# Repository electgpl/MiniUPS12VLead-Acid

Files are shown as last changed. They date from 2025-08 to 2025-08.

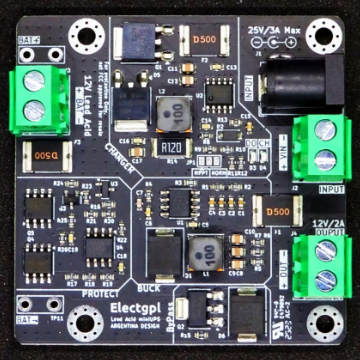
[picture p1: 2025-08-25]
Resources/Captura de pantalla 2025-08-25 201650.png

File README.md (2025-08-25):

# Mini UPS 12V Lead-Acid | UVP Protector - Buck - Charger - Bypass

This project implements a **mini uninterruptible power supply (UPS)** designed for **12V Lead-Acid AGM/GEL batteries**.  
It integrates a dedicated **CN3767 lead-acid charger**, a **PMOS + Schottky bypass circuit**, a **TPS54360 buck regulator**, and an **undervoltage protection (UVP)** stage to ensure safe battery operation.  

The design focuses on maintaining stable 12V output while protecting the battery from undervoltage damage and ensuring correct charging cycles.  

---

## 🔑 Features

- **Battery chemistry supported:** 12V Lead-Acid (AGM, GEL).  
- **CN3767-based lead-acid charger** with constant-current/constant-voltage (CC/CV) charging.  
- **Bypass system:**  
  - PMOS + Schottky switch circuit.  
  - During charging, disconnects the battery from the load to allow proper charging.  
  - The load is powered instead by a regulated buck supply.  
- **Buck regulator stage:**  
  - Based on **TPS54360** DC/DC converter.  
  - Configured to **13.8V output** for stable system powering during battery charge.  
- **Undervoltage protection (UVP):**  
  - Implemented with **LM393 comparator** and **TL431 reference**.  
  - Controls a **back-to-back PMOS switch**.  
  - Cuts off the battery when voltage falls below **11V**.  
  - Latch-off behavior: system remains disconnected until external power is restored.  
- **2-layer PCB**, designed for compact size, thermal management, and robust operation.  

---

## 📂 Repository structure

- **/schematic/** → Circuit schematic files.  
- **/pcb/** → PCB layout files ready for fabrication.  
- **/doc/** → Technical notes and design explanation.  
- **/img/** → PCB renders and prototype photos.  

---

## 🔧 Typical applications

- DIY 12V backup supply for small systems.  
- Router, modem, or IoT device UPS.  
- Low-power embedded controllers requiring uninterrupted 12V operation.  
- Safe battery-powered test benches.  

---

## 📑 References

- [CN3767 Datasheet (Consonance)](http://www.consonance-elec.com/pdf/datasheet/DSE-CN3767.pdf)  
- [TPS54360 Datasheet (Texas Instruments)](https://www.ti.com/lit/ds/symlink/tps54360.pdf)  
- [LM393 Datasheet (Texas Instruments)](https://www.ti.com/lit/ds/symlink/lm393.pdf)  
- [TL431 Reference Datasheet (Texas Instruments)](https://www.ti.com/lit/ds/symlink/tl431.pdf)  

---

## 📸 Project preview

*(Insert here PCB renders and/or real prototype images)*  

---

## ⚖️ License

This project is released under the **MIT License**.  
You are free to use, modify, and distribute it, provided that proper credit is given.  

---

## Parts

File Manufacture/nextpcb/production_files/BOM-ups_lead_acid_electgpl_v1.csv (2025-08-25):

MPN | Qty | Designator | value | manufacturer | Category | SKU | Customer Supply | Customer Remark
 | 13 | C4,C2,C18,C1,C19,C6,C15,C13,C7,C3,C14,C16,C5 | 2u2
 | 6 | C11,C8,C17,C12,C10,C9 | 47u
 | 1 | D2 | 5V1
 | 2 | D4,D3 | LED
 | 2 | D5,Q1 | MBRD20100CT
 | 2 | D6,D1 | SS54
 | 3 | F1,F2,F3 | 500/24N
 | 4 | H1,H3,H4,H2 | MountingHole_Pad
 | 1 | J1 | Barrel_Jack_Switch
 | 3 | J2,J4,J3 | Screw_Terminal_01x02
 | 1 | JP1 | MPPT
 | 2 | L2,L1 | 10u
 | 1 | Q2 | NTF6P02
 | 2 | Q3,U3 | 2N7002
 | 2 | Q4,Q5 | AO4407
 | 25 | R11,R8,R1,R25,R13,R21,R26,R3,R6,R10,R19,R24,R12,R22,R17,R4,R15,R5,R7,R2,R9,R20,R16,R23,R18 | 100k
 | 1 | R14 | 0R12
 | 2 | TP11,TP10 | TestPoint_Alt
 | 1 | U1 | TPS54360DDA
 | 1 | U2 | CN3767
 | 1 | U4 | LM393

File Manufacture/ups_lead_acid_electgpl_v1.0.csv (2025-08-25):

Qty | Reference | Value | Footprint | DNP | LCSC | MFR P/N
4 | C1,C2,C3,C4 | 2u2 | Capacitor_SMD:C_0603_1608Metric |  | C913904 | CL10A225KB8NNNC
5 | C5,C13,C14,C16,C18 | 100n | Capacitor_SMD:C_0603_1608Metric |  | C1591 | CL10B104KB8NNNC
1 | C6 | 4n7 | Capacitor_SMD:C_0603_1608Metric |  | C1621 | CL10B472KB8NNNC
1 | C7 | 47p | Capacitor_SMD:C_0603_1608Metric |  | C1671 | CL10C470JB8NNNC
6 | C8,C9,C10,C11,C12,C17 | 47u | Capacitor_SMD:C_0805_2012Metric |  | C602037 | CL21A226MAYNNNE
1 | C15 | 220n | Capacitor_SMD:C_0603_1608Metric |  | C64705 | CL10B224KB8NNNC
1 | C19 | 10n | Capacitor_SMD:C_0603_1608Metric |  | C1589 | CL10B103KB8NNNC
2 | D1,D6 | SS54 | Diode_SMD:D_SMC |  | C5199108 | SS54
1 | D2 | 5V1 | Diode_SMD:D_SOD-123 |  | C66198 | MMSZ5231BT1G
2 | D3,D4 | LED | LED_SMD:LED_0603_1608Metric |  | C965802 | XL-1608UYC-06
1 | D5 | MBRD20100CT | Package_TO_SOT_SMD:TO-252-2 |  | C460890 | MBRD20100CT-13
3 | F1,F2,F3 | 500/24N | Fuse:Fuse_2920_7451Metric |  | C6165172 | SMD2920-500/24N
4 | H1,H2,H3,H4 | MountingHole_Pad | MountingHole:MountingHole_3.2mm_M3_Pad_Via | DNP
1 | J1 | Barrel_Jack_Switch | Connector_BarrelJack:BarrelJack_GCT_DCJ200-10-A_Horizontal |  | C194407 | DC-470-2.1GP
3 | J2,J3,J4 | Screw_Terminal_01x02 | TerminalBlock_RND:TerminalBlock_RND_205-00232_1x02_P5.08mm_Horizontal |  | C8465 | WJ500V-5.08-2P
1 | JP1 | MPPT | Jumper:SolderJumper-3_P1.3mm_Open_Pad1.0x1.5mm | DNP
2 | L1,L2 | 10u | Inductor_SMD:L_Taiyo-Yuden_NR-60xx |  | C360734 | VLS6045EX-100M
1 | Q1 | DMP4051LK3-13 | Package_TO_SOT_SMD:TO-252-2 |  | C397952 | DMP4051LK3-13
1 | Q2 | NTF6P02 | Package_TO_SOT_SMD:SOT-223-3_TabPin2 |  | C558214 | NTF6P02T3G-VB
1 | Q3 | 2N7002 | Package_TO_SOT_SMD:SOT-23 |  | C65189 | 2N7002,215
2 | Q4,Q5 | AO4407 | Package_SO:SOP-8_3.9x4.9mm_P1.27mm |  | C2841482 | AO4407A
1 | R1 | 442k | Resistor_SMD:R_0603_1608Metric |  | C23175 | 0603WAF4423T5E
1 | R2 | 90k9 | Resistor_SMD:R_0603_1608Metric |  | C2930136 | FRC0603F9092TS
1 | R3 | 243k | Resistor_SMD:R_0603_1608Metric |  | C7467321 | FRC0603F2433TS
1 | R4 | 16k9 | Resistor_SMD:R_0603_1608Metric |  | C2933158 | FRC0603F1692TS
1 | R5 | 49R9 | Resistor_SMD:R_0603_1608Metric |  | C2930110 | FRC0603F49R9TS
1 | R6 | 33k | Resistor_SMD:R_0603_1608Metric |  | C2907153 | FRC0603J333 TS
1 | R7 | 2k2 | Resistor_SMD:R_0603_1608Metric |  | C2907117 | FRC0603J222 TS
3 | R8,R11,R15 | 100k | Resistor_SMD:R_0603_1608Metric |  | C2907088 | FRC0603J104 TS
1 | R9 | 1M | Resistor_SMD:R_0603_1608Metric |  | C2907003 | FRC0603F1004TS
1 | R10 | 360k | Resistor_SMD:R_0603_1608Metric |  | C2907029 | FRC0603F3603TS
6 | R12,R16,R22,R23,R24,R26 | 10k | Resistor_SMD:R_0603_1608Metric |  | C2930027 | FRC0603J103 TS
1 | R13 | 120R | Resistor_SMD:R_0603_1608Metric |  | C2907096 | FRC0603J121 TS
1 | R14 | 0R12 | Resistor_SMD:R_2512_6332Metric |  | C875871 | PT2512FK-7W0R12L
3 | R17,R18,R19 | 47k | Resistor_SMD:R_0603_1608Metric |  | C2907042 | FRC0603F4702TS
1 | R20 | 15k | Resistor_SMD:R_0603_1608Metric |  | C2906995 | FRC0603F1502TS
1 | R21 | 4k7 | Resistor_SMD:R_0603_1608Metric |  | C2907166 | FRC0603J472 TS
1 | R25 | 10R | Resistor_SMD:R_0603_1608Metric |  | C2907091 | FRC0603J100 TS
2 | TP10,TP11 | TestPoint_Alt | TestPoint:TestPoint_Bridge_Pitch5.08mm_Drill1.3mm | DNP
1 | U1 | TPS54360DDA | Package_SO:HSOP-8-1EP_3.9x4.9mm_P1.27mm_EP2.41x3.1mm_ThermalVias |  | C44377 | TPS54360DDAR
1 | U2 | CN3767 | Package_SO:SSOP-10_3.9x4.9mm_P1.00mm |  | C81968 | CN3767
1 | U3 | TL431AIDBZR | Package_TO_SOT_SMD:SOT-23 |  | C23892 | TL431AIDBZR
1 | U4 | LM393 | Package_SO:SOIC-8_3.9x4.9mm_P1.27mm |  | C67470 | LM393DR

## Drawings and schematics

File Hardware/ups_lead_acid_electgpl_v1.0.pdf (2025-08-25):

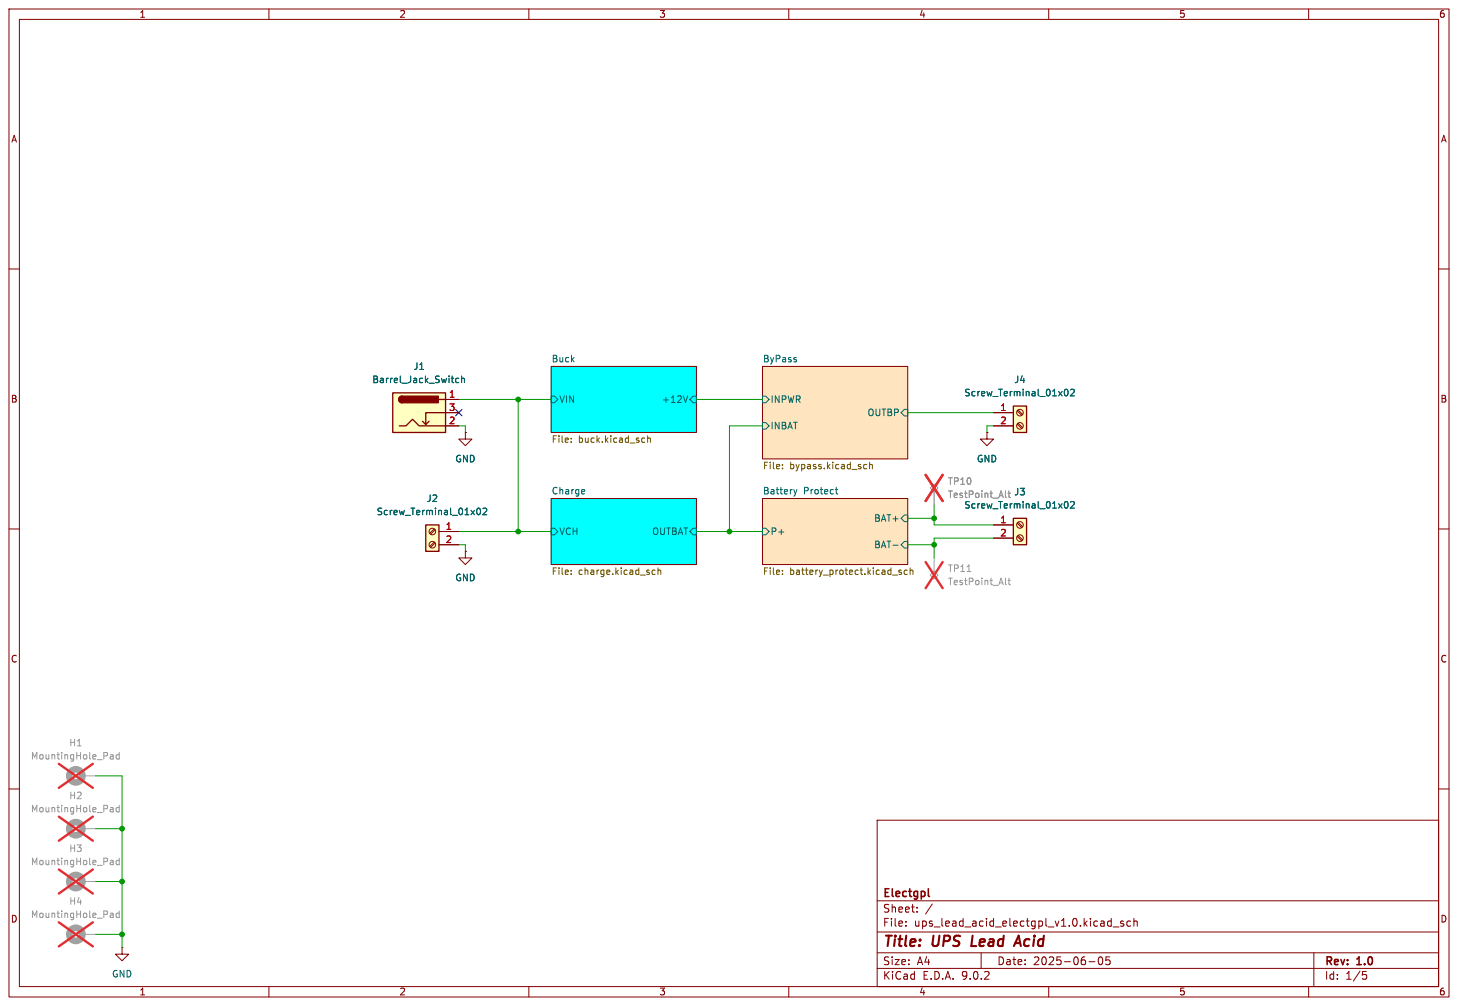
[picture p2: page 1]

ByPass File: bypass.kicad_sch BAT+ BAT- P+ Battery Protect File: battery_protect.kicad_sch GND

Id: 1/5 Title: UPS Lead Acid

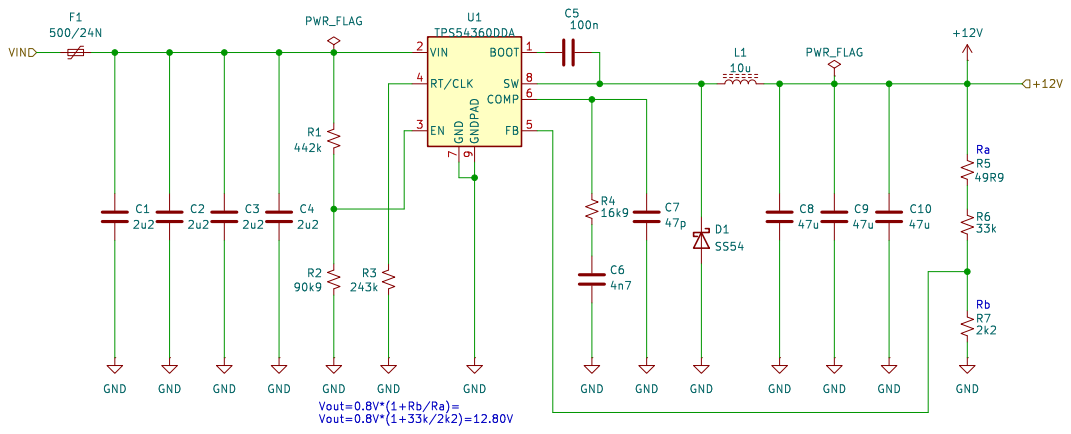
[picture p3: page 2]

9 BOOT 1 SW 8 COMP 6 FB 5 U1 TPS54360DDA R3

File: buck.kicad_sch Sheet: /Buck/ Electgpl

Id: 2/5 Title: UPS Lead Acid

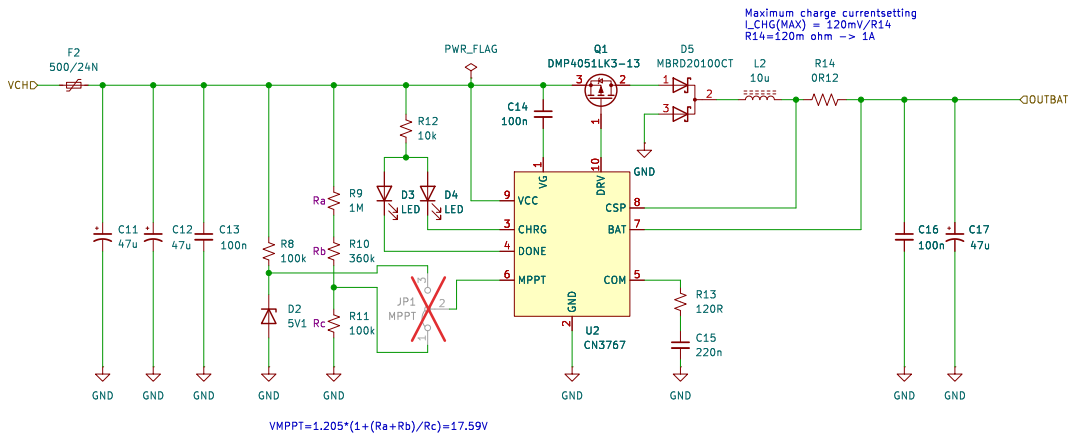
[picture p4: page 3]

2 DRV 10 CSP 8 BAT 7 COM 5 D3
360k RbGND

2 DRV 10 CSP 8 BAT 7 COM 5 U2 CN3767 GND

File: charge.kicad_sch Sheet: /Charge/
Id: 3/5 Title: UPS Lead Acid

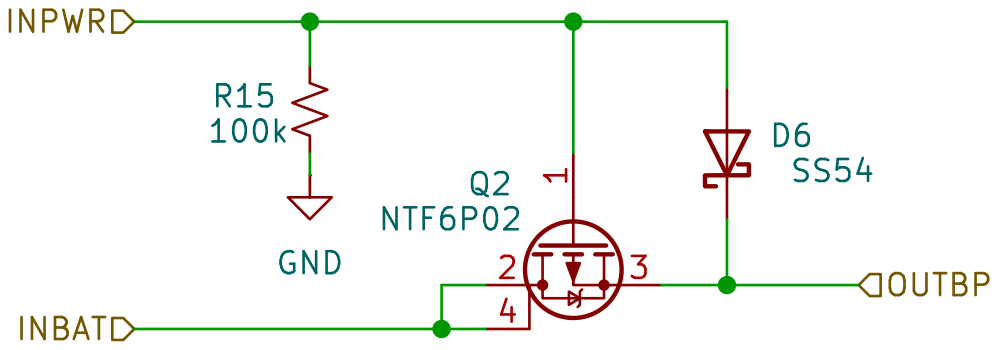
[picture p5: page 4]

Electgpl
File: bypass.kicad_sch Sheet: /ByPass/
Id: 4/5 Title: UPS Lead Acid

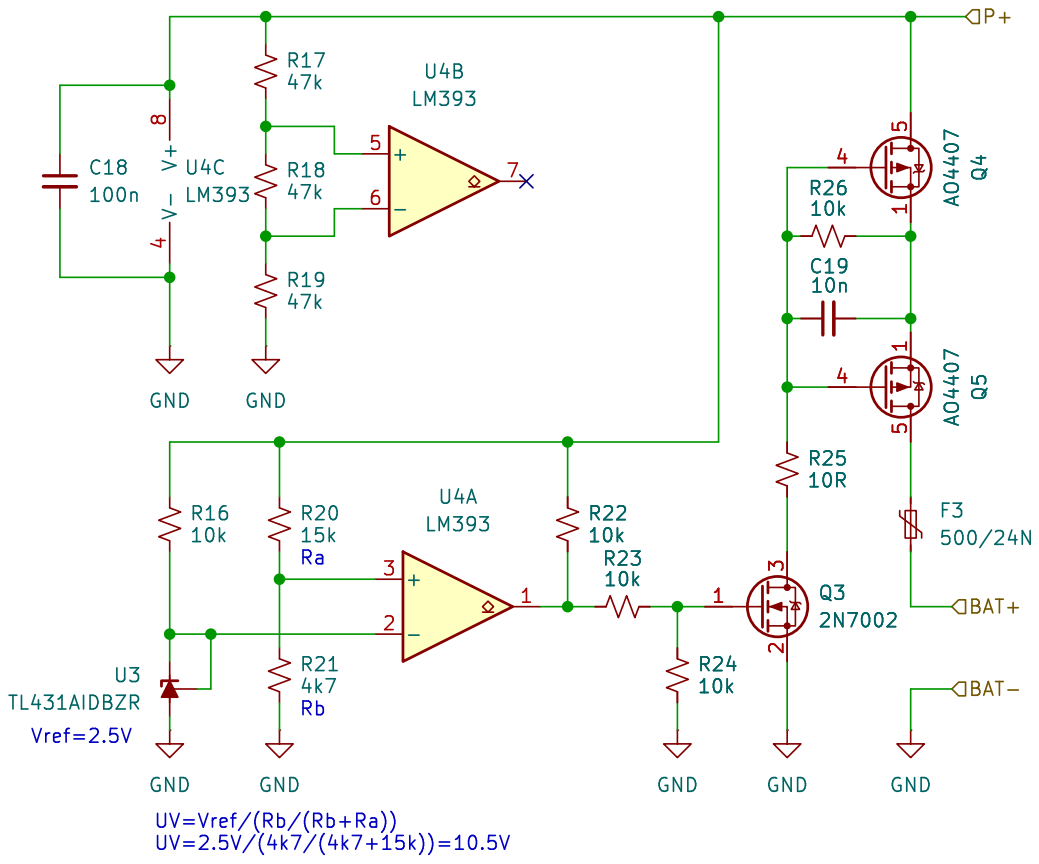
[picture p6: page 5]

Id: 5/5 Title: UPS Lead Acid

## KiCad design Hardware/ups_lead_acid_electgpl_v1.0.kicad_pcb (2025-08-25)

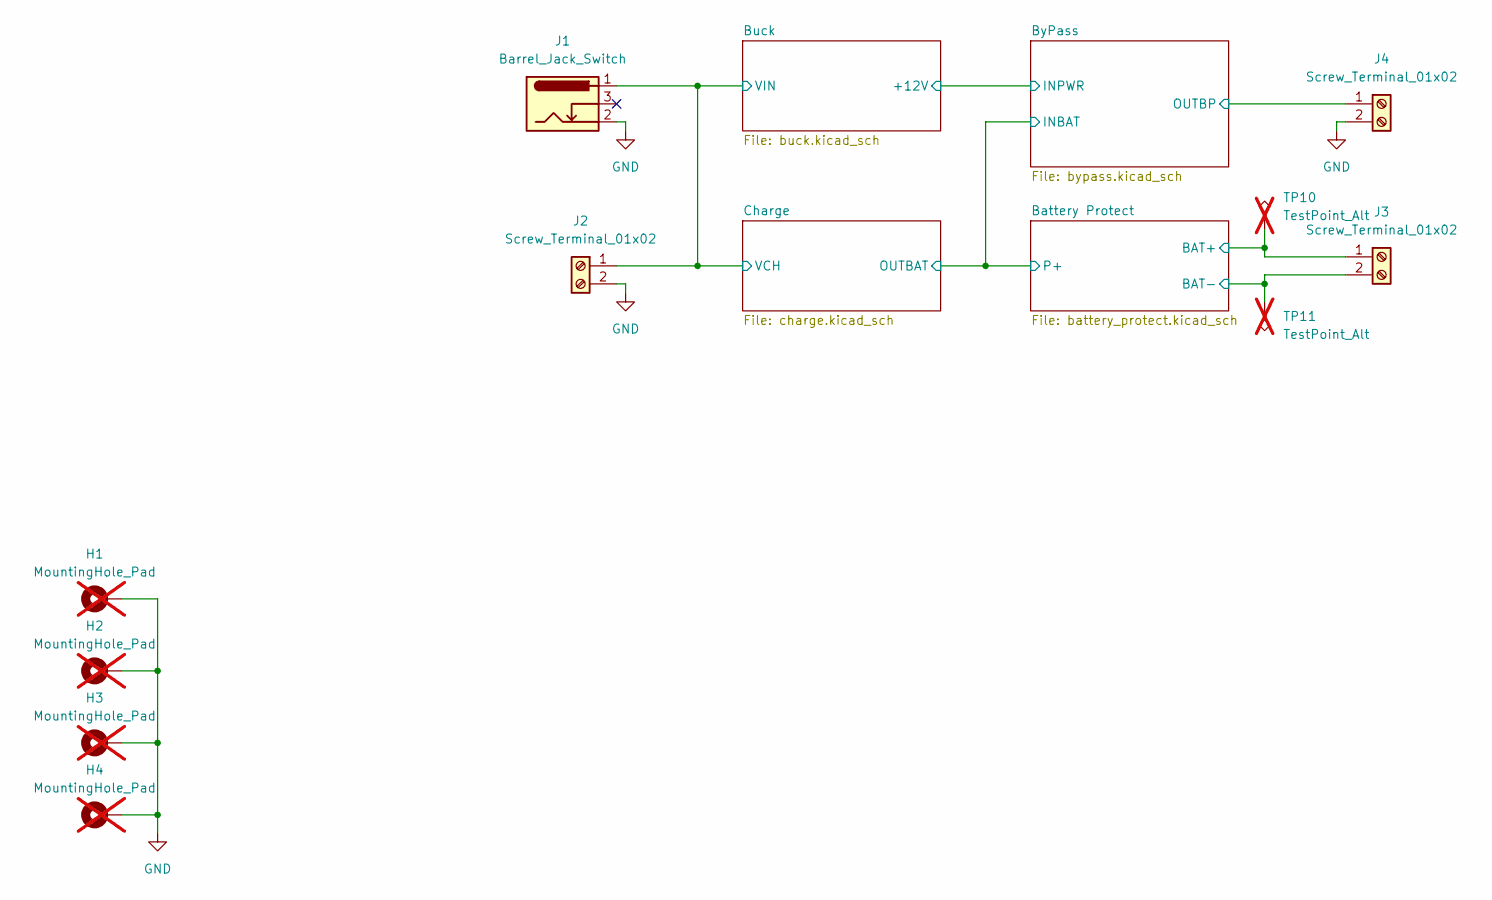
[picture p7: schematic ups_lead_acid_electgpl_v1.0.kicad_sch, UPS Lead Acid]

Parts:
H1, H2, H3, H4: MountingHole_Pad; MountingHole_3.2mm_M3_Pad_Via; not fitted
J1: Barrel_Jack_Switch; BarrelJack_GCT_DCJ200-10-A_Horizontal; MFR P/N DC-470-2.1GP; LCSC C194407
J2, J3, J4: Screw_Terminal_01x02; TerminalBlock_RND_205-00232_1x02_P5.08mm_Horizontal; MFR P/N WJ500V-5.08-2P; LCSC C8465
TP10, TP11: TestPoint_Alt; TestPoint_Bridge_Pitch5.08mm_Drill1.3mm; not fitted

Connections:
/Battery Protect/BAT+: J3.1, TP10.1; also elsewhere on the board
/Buck/VIN: J1.1, J2.1; also elsewhere on the board
/ByPass/OUTBP: J4.1; also elsewhere on the board
GND: H1.1, H2.1, H3.1, H4.1, J1.2, J2.2, J3.2, J4.2, TP11.1; also elsewhere on the board

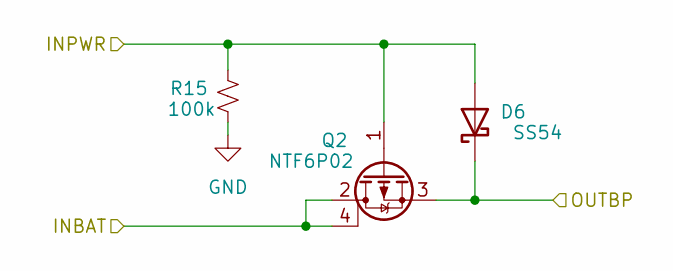
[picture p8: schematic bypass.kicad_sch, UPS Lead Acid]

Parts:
D6: SS54; D_SMC; MFR P/N SS54; LCSC C5199108
Q2: NTF6P02; SOT-223-3_TabPin2; MFR P/N NTF6P02T3G-VB; LCSC Part C154901
R15: 100k; R_0603_1608Metric; MFR P/N FRC0603J104 TS; LCSC Part C99198

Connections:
+12V: D6.2 (A), Q2.1 (G), R15.2; also elsewhere on the board
/Battery Protect/P+: Q2.2 (D), Q2.4 (D); also elsewhere on the board
/ByPass/OUTBP: D6.1 (K), Q2.3 (S); also elsewhere on the board
GND: R15.1; also elsewhere on the board

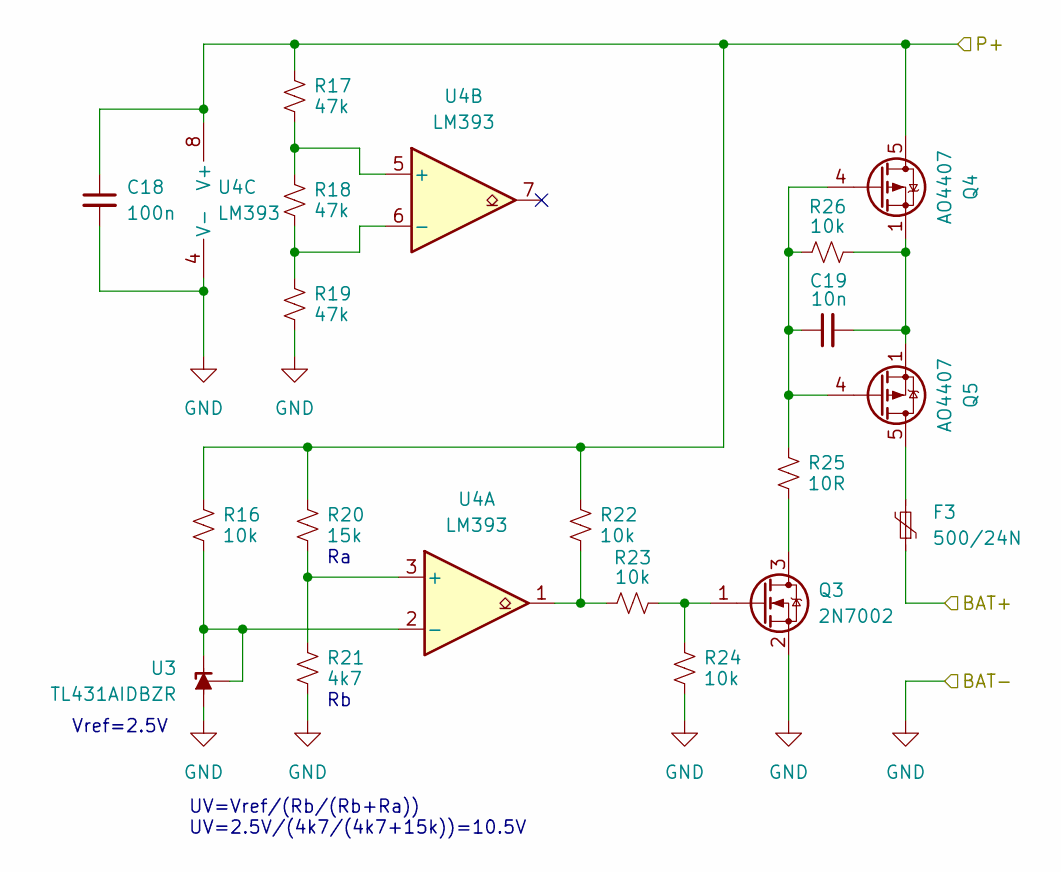
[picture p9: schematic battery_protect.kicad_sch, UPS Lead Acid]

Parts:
C18: 100n; C_0603_1608Metric; MFR P/N CL10B104KB8NNNC; LCSC C1591
C19: 10n; C_0603_1608Metric; MFR P/N CL10B103KB8NNNC; LCSC C1589
F3: 500/24N; Fuse_2920_7451Metric; MFR P/N SMD2920-500/24N; LCSC C6165172
Q3: 2N7002; SOT-23; MFR P/N 2N7002,215; LCSC C65189
Q4, Q5: AO4407; SOP-8_3.9x4.9mm_P1.27mm; MFR P/N AO4407A; LCSC C2841482
R16, R22, R23, R24, R26: 10k; R_0603_1608Metric; MFR P/N FRC0603J103 TS; LCSC C2930027
R17, R18, R19: 47k; R_0603_1608Metric; MFR P/N FRC0603F4702TS; LCSC C2907042
R20: 15k; R_0603_1608Metric; MFR P/N FRC0603F1502TS; LCSC C2906995
R21: 4k7; R_0603_1608Metric; MFR P/N FRC0603J472 TS; LCSC C2907166
R25: 10R; R_0603_1608Metric; MFR P/N FRC0603J100 TS; LCSC C2907091
U3: TL431AIDBZR; SOT-23; MFR P/N TL431AIDBZR; LCSC C23892
U4: LM393; SOIC-8_3.9x4.9mm_P1.27mm; MFR P/N LM393DR; LCSC C67470

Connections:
/Battery Protect/BAT+: F3.1; also elsewhere on the board
/Battery Protect/P+: C18.1, Q4.5 (D), Q4.6 (D), Q4.7 (D), Q4.8 (D), R16.1, R17.1, R20.1, R22.1, U4.8 (V+); also elsewhere on the board
GND: C18.2, Q3.2 (S), R19.2, R21.2, R24.2, U3.3 (A), U4.4 (V-); also elsewhere on the board
unnamed: C19.2, Q4.1 (S), Q4.2 (S), Q4.3 (S), Q5.1 (S), Q5.2 (S), Q5.3 (S), R26.2
unnamed: F3.2, Q5.5 (D), Q5.6 (D), Q5.7 (D), Q5.8 (D)
unnamed: Q3.3 (D), R25.2
unnamed: Q3.1 (G), R23.2, R24.1
unnamed: C19.1, Q4.4 (G), Q5.4 (G), R25.1, R26.1
unnamed: R22.2, R23.1, U4.1
unnamed: R16.2, U3.1 (K), U3.2 (REF), U4.2 (-)
unnamed: R20.2, R21.1, U4.3 (+)
unnamed: R17.2, R18.1, U4.5 (+)
unnamed: R18.2, R19.1, U4.6 (-)

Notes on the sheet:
UV=Vref/(Rb/(Rb+Ra)) UV=2.5V/(4k7/(4k7+15k))=10.5V
Vref=2.5V

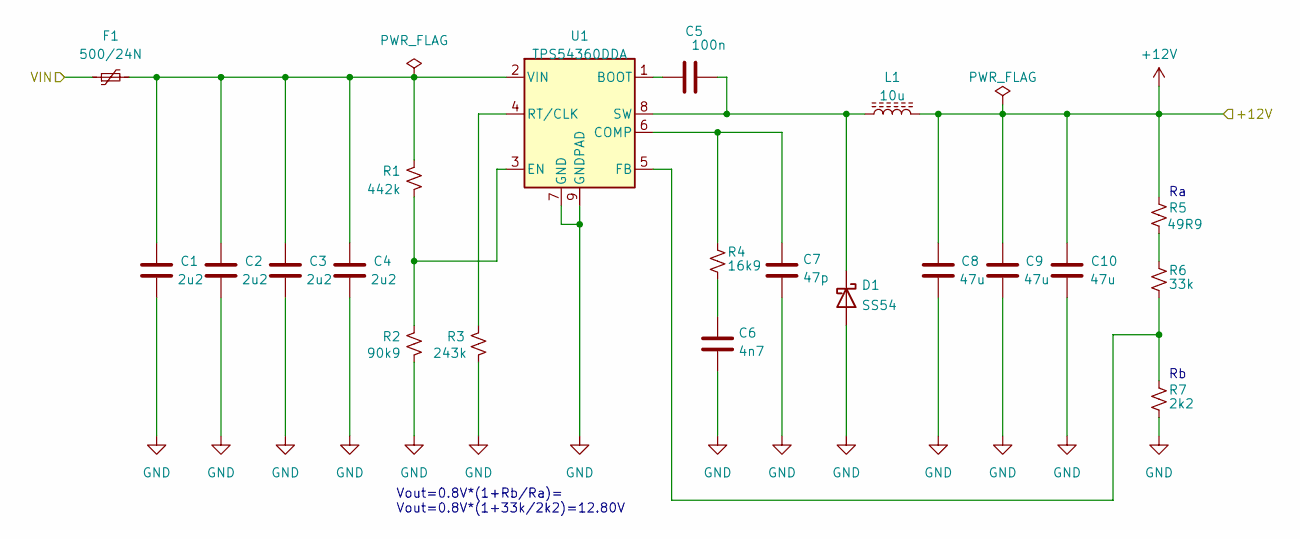
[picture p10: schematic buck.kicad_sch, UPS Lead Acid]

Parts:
C1, C2, C3, C4: 2u2; C_0603_1608Metric; MFR P/N CL10A225KB8NNNC; LCSC C913904
C5: 100n; C_0603_1608Metric; MFR P/N CL10B104KB8NNNC; LCSC C1591
C6: 4n7; C_0603_1608Metric; MFR P/N CL10B472KB8NNNC; LCSC C1621
C7: 47p; C_0603_1608Metric; MFR P/N CL10C470JB8NNNC; LCSC C1671
C8, C9, C10: 47u; C_0805_2012Metric; MFR P/N CL21A226MAYNNNE; LCSC C602037
D1: SS54; D_SMC; MFR P/N SS54; LCSC C5199108
F1: 500/24N; Fuse_2920_7451Metric; MFR P/N SMD2920-500/24N; LCSC C6165172
L1: 10u; L_Taiyo-Yuden_NR-60xx; MFR P/N VLS6045EX-100M; LCSC C360734
R1: 442k; R_0603_1608Metric; MFR P/N 0603WAF4423T5E; LCSC C23175
R2: 90k9; R_0603_1608Metric; MFR P/N FRC0603F9092TS; LCSC C2930136
R3: 243k; R_0603_1608Metric; MFR P/N FRC0603F2433TS; LCSC C7467321
R4: 16k9; R_0603_1608Metric; MFR P/N FRC0603F1692TS; LCSC C2933158
R5: 49R9; R_0603_1608Metric; MFR P/N FRC0603F49R9TS; LCSC C2930110
R6: 33k; R_0603_1608Metric; MFR P/N FRC0603J333 TS; LCSC C2907153
R7: 2k2; R_0603_1608Metric; MFR P/N FRC0603J222 TS; LCSC C2907117
U1: TPS54360DDA; HSOP-8-1EP_3.9x4.9mm_P1.27mm_EP2.41x3.1mm_ThermalVias; MFR P/N TPS54360DDAR; LCSC C44377

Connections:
+12V: C8.2, C9.2, C10.2, L1.2, R5.1; also elsewhere on the board
/Buck/VIN: F1.1; also elsewhere on the board
GND: C1.1, C2.1, C3.1, C4.1, C6.2, C7.2, C8.1, C9.1, C10.1, D1.2 (A), R2.2, R3.2, R7.2, U1.7 (GND), U1.9 (GNDPAD); also elsewhere on the board
unnamed: C6.1, R4.2
unnamed: C5.2, D1.1 (K), L1.1, U1.8 (SW)
unnamed: R5.2, R6.1
unnamed: C5.1, U1.1 (BOOT)
unnamed: C7.1, R4.1, U1.6 (COMP)
unnamed: R1.2, R2.1, U1.3 (EN)
unnamed: R6.2, R7.1, U1.5 (FB)
unnamed: R3.1, U1.4 (RT/CLK)
unnamed: C1.2, C2.2, C3.2, C4.2, F1.2, R1.1, U1.2 (VIN)

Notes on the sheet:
Vout=0.8V*(1+Rb/Ra)= Vout=0.8V*(1+33k/2k2)=12.80V

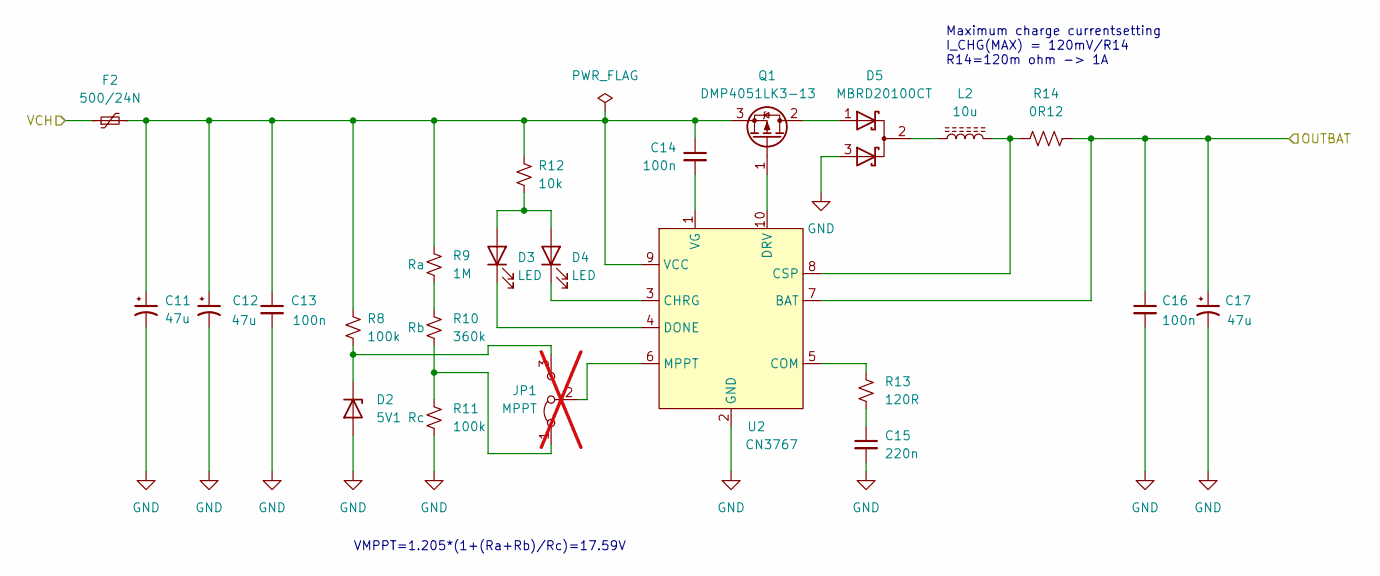
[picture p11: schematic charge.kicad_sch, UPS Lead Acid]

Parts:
C11, C12, C17: 47u; C_0805_2012Metric; MFR P/N CL21A226MAYNNNE; LCSC C602037
C13, C14, C16: 100n; C_0603_1608Metric; MFR P/N CL10B104KB8NNNC; LCSC C1591
C15: 220n; C_0603_1608Metric; MFR P/N CL10B224KB8NNNC; LCSC C64705
D2: 5V1; D_SOD-123; MFR P/N MMSZ5231BT1G; LCSC C66198
D3, D4: LED; LED_0603_1608Metric; MFR P/N XL-1608UYC-06; LCSC C965802
D5: MBRD20100CT; TO-252-2; MFR P/N MBRD20100CT-13; LCSC C460890
F2: 500/24N; Fuse_2920_7451Metric; MFR P/N SMD2920-500/24N; LCSC C6165172
JP1: MPPT; SolderJumper-3_P1.3mm_Open_Pad1.0x1.5mm; not fitted
L2: 10u; L_Taiyo-Yuden_NR-60xx; MFR P/N VLS6045EX-100M; LCSC C360734
Q1: DMP4051LK3-13; TO-252-2; MFR P/N DMP4051LK3-13; LCSC C397952
R8, R11: 100k; R_0603_1608Metric; MFR P/N FRC0603J104 TS; LCSC C2907088
R9: 1M; R_0603_1608Metric; MFR P/N FRC0603F1004TS; LCSC C2907003
R10: 360k; R_0603_1608Metric; MFR P/N FRC0603F3603TS; LCSC C2907029
R12: 10k; R_0603_1608Metric; MFR P/N FRC0603J103 TS; LCSC C2930027
R13: 120R; R_0603_1608Metric; MFR P/N FRC0603J121 TS; LCSC C2907096
R14: 0R12; R_2512_6332Metric; MFR P/N PT2512FK-7W0R12L; LCSC C875871
U2: CN3767; SSOP-10_3.9x4.9mm_P1.00mm; MFR P/N CN3767; LCSC C81968

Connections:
/Battery Protect/P+: C16.1, C17.1, R14.2, U2.7 (BAT); also elsewhere on the board
/Buck/VIN: F2.1; also elsewhere on the board
GND: C11.2, C12.2, C13.2, C15.2, C16.2, C17.2, D2.2 (A), D5.3 (A), R11.2, U2.2 (GND); also elsewhere on the board
unnamed: C15.1, R13.2
unnamed: D2.1 (K), JP1.3 (B), R8.2
unnamed: D3.2 (A), D4.2 (A), R12.2
unnamed: D3.1 (K), U2.4 (DONE)
unnamed: D4.1 (K), U2.3 (CHRG)
unnamed: D5.2 (K), L2.1
unnamed: JP1.1 (A), R10.2, R11.1
unnamed: JP1.2 (C), U2.6 (MPPT)
unnamed: D5.1 (A), Q1.2 (D)
unnamed: Q1.1 (G), U2.10 (DRV)
unnamed: C11.1, C12.1, C13.1, C14.1, F2.2, Q1.3 (S), R8.1, R9.1, R12.1, U2.9 (VCC)
unnamed: R9.2, R10.1
unnamed: R13.1, U2.5 (COM)
unnamed: L2.2, R14.1, U2.8 (CSP)
unnamed: C14.2, U2.1 (VG)

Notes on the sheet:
VMPPT=1.205*(1+(Ra+Rb)/Rc)=17.59V
Maximum charge currentsetting I_CHG(MAX) = 120mV/R14 R14=120m ohm -> 1A

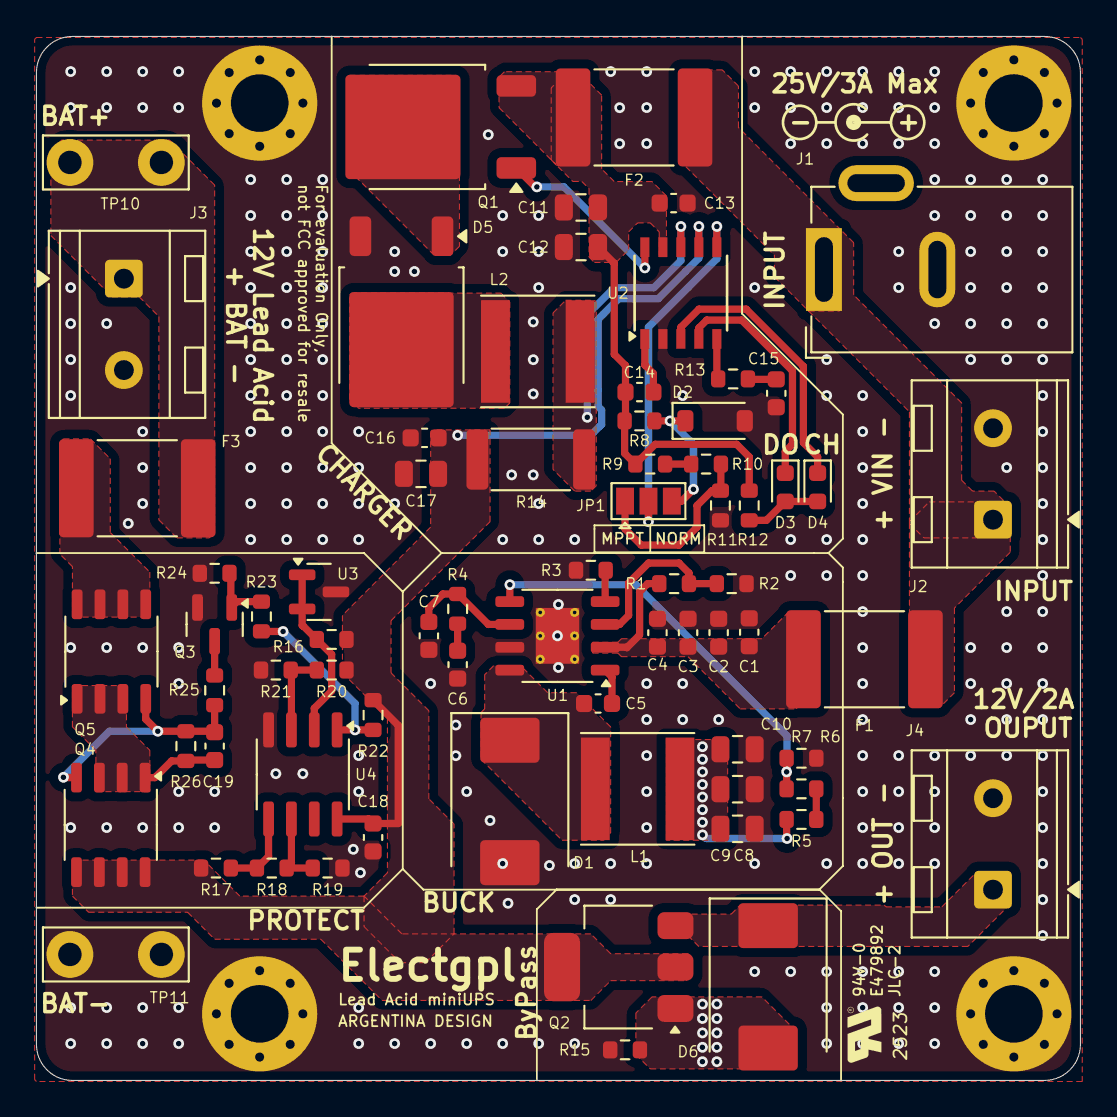
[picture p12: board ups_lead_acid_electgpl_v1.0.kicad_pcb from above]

Board: 2 copper layers, 58.0 x 58.0 mm, 76 parts (0 on the bottom side), 40 nets.
